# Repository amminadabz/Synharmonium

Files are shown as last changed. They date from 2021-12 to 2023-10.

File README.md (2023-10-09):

# The Synharmonium
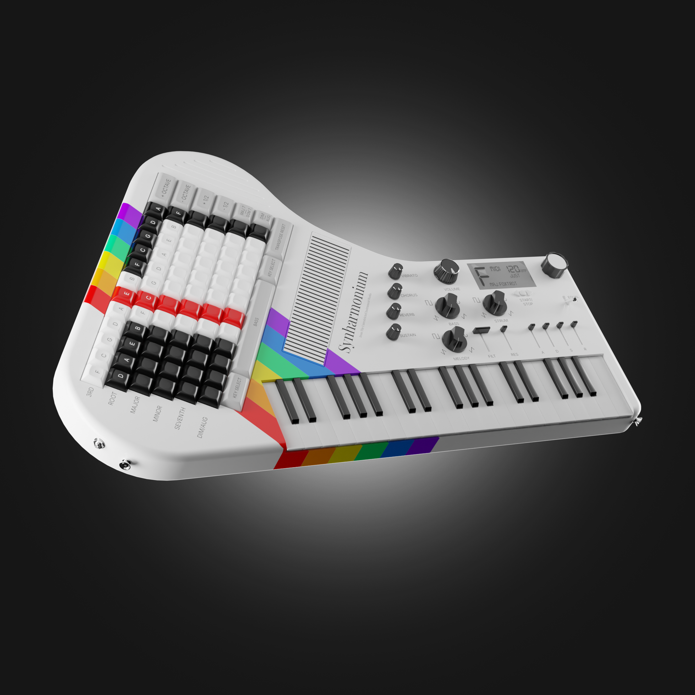
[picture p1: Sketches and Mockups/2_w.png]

#### is a new kind of musical instrument.
Designed to be easy to use, and more importantly, easy to make good music with. It uses the accordion's Stradella bass system to make it easy to play notes and chords that go well together, the Omnichord's strum plate to give texture to that harmony, and a piano keyboard for a familiar way to add a melody.

## A Well-Tempered synthesizer.
One of the goals of the Synharmonium is to create an instrument which uses an algorithmic implementation of just intonation. In other words, it tunes every note in a perfect mathematical relation to the root of whatever chord is being played. Where other instruments simply have every note an equal distance apart and call it done ("Equal Temperament"), the Synharmonium will ensure they are always in simple ratios to each other, allowing for a more resonant sound. But if you want to play _with_ those other instruments, you always have the option to disable this feature and return to the more common tuning.

## Digital where it's needed, analogue where it counts.
The Synharmonium uses a digital system to implement that tuning algorithm. But once the computer has decided what frequencies are best, everything that can analogue will be, including the envelope generators, drum machine oscillators, and effects. This allows it to have that classic analogue sound with none of the downsides.

But, if you want to use the Synharmonium's tuning technology with an external synthesizer, it also has full MIDI compatibility (with both DIN and USB).

## Free to build, modify, and hack
The hardware and software are all open source. I intend to base the control and tuning systems on an Arduino, which is beginner-friendly and hackable by design. I haven't the means to build these machines on a large scale at the moment (though I've thought about selling an "official version" as a preassembled machine and a kit, lmk what y'all think), so for the time being I will just be providing the design for free. That means you get to build it (!) until I know what I'm doing.

## A work in progress.
I'll be real with y'all: I don't know what I'm doing. Every part of this project is a skill that I am learning as I go. But I think this is a thing that deserves to exist, so I intend to let it. It will probably take some time, as I am currently pursuing degrees in Electrical Engineering and Computer Engineering, so I can only work on the Synharmonium in my free time.

If you have skills that could help this process along, feel free to join the project. Do [send me an email](mailto:uiwmusic@proton.me) first though, I'd like to know who I'm working with! 

Here goes nothin'!

-Evan

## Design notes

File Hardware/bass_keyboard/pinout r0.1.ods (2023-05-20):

floppy pin | breadboard pin | arduino pin | value
1 | E1 | +5V | VCC
2 | E2 | 22 | D92
3 | E3 | 23 | D93
4 | E4 | 24 | D94
5 | E5 | 25 | D95
6 | E6 |  | NC
7 | E7 |  | NC
8 | E8 |  | NC
9 | E9 |  | NC
10 | E10 |  | NC
11 | E11 |  | NC
12 | E12 | 27 | ROW5
13 | E13 | 28 | ROW4
14 | E14 | 29 | ROW3
15 | E15 | 30 | ROW2
16 | E16 | 31 | ROW1
17 | E17 | 32 | ROW0
18 | F1 |  | NC
19 | F2 | GND | LS1-
20 | F3 | 13 | LS1+
21 | F4 | 33 | COL12
22 | F5 | 34 | COL11
23 | F6 | 35 | COL10
24 | F7 | 36 | COL9
25 | F8 | 37 | COL8
26 | F9 | 38 | COL7
27 | F10 | 39 | COL6
28 | F11 | 40 | COL5
29 | F12 | 41 | COL4
30 | F13 | 42 | COL3
31 | F14 | 43 | COL2
32 | F15 | 44 | COL1
33 | F16 | 45 | COL0
34 | F17 | 26 | ROW6

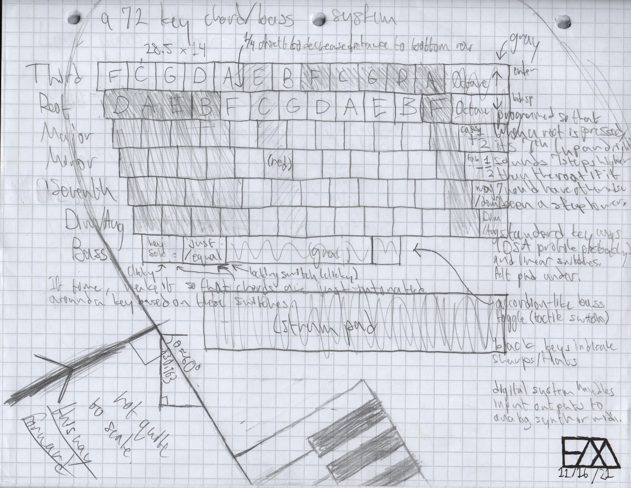
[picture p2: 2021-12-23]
Sketches and Mockups/synharmonium-sketch-1.jpg

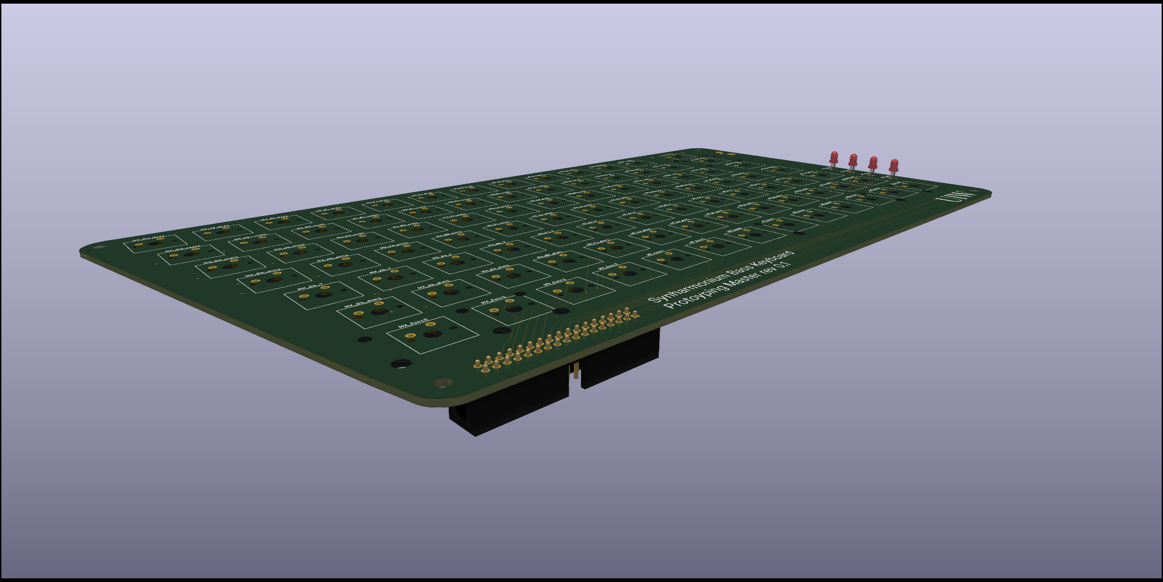
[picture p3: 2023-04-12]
Sketches and Mockups/bass_keyboard_pcb_render_frontdiag.png

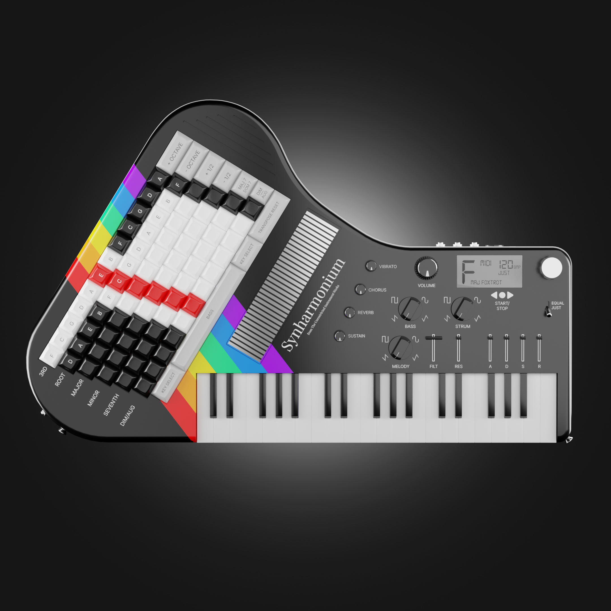
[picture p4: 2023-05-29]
Sketches and Mockups/1_b.png

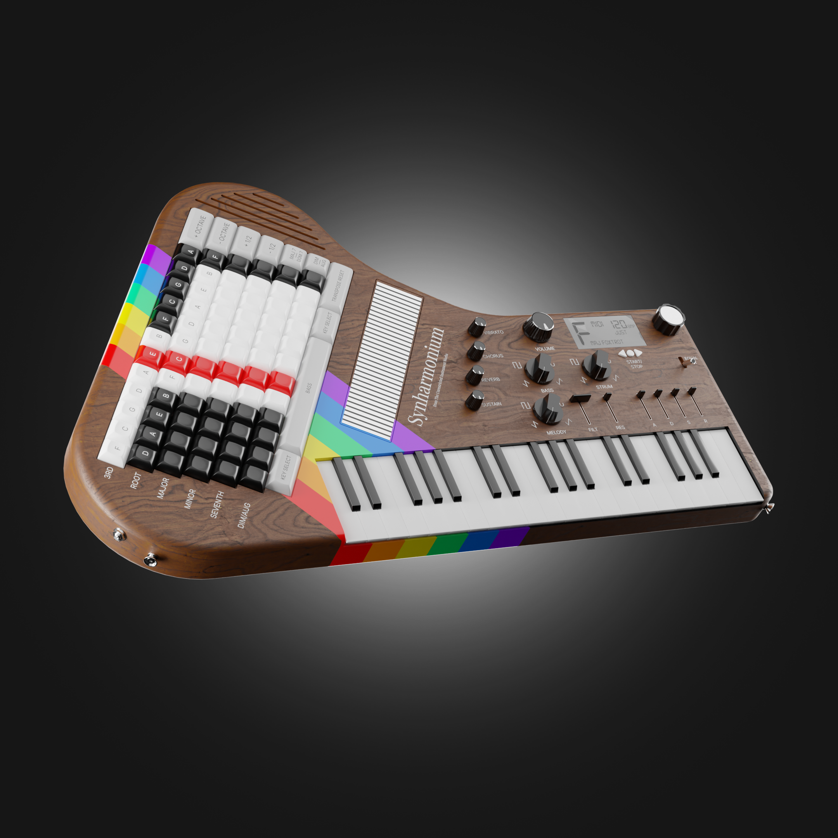
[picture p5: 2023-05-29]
Sketches and Mockups/2_wood.png

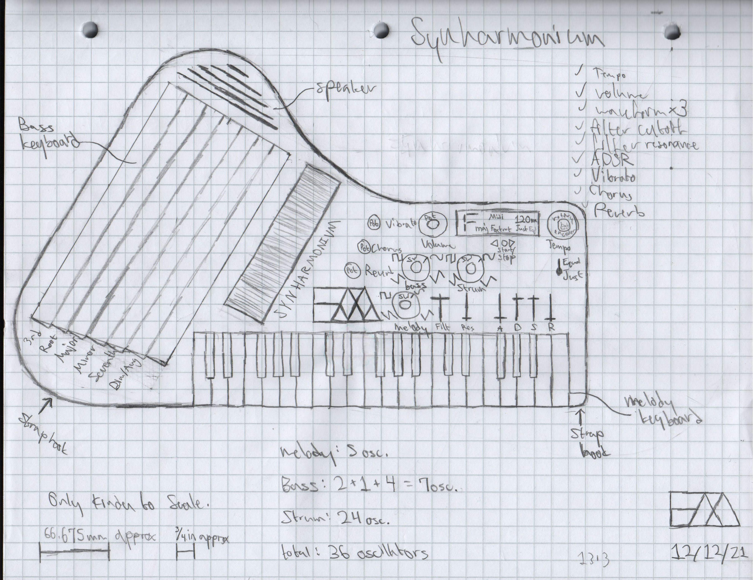
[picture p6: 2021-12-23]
Sketches and Mockups/synharmonium-sketch-2.jpg

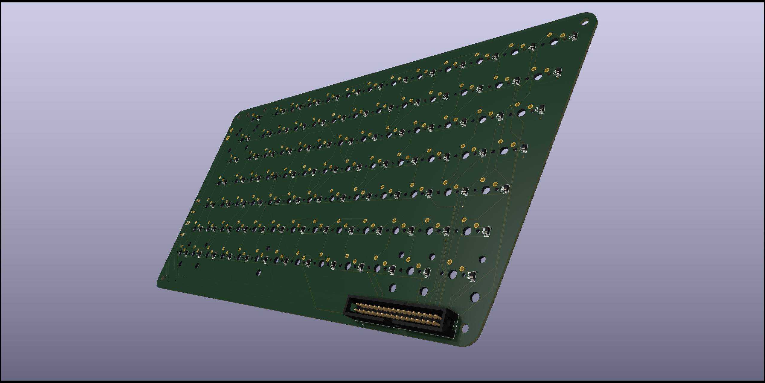
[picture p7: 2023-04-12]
Sketches and Mockups/bass_keyboard_pcb_render_backdiag.png

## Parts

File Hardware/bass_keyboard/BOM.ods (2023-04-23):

UIW
 |  | ™ | The Unrestricted Instrumentworks
 |  |  | Synharmonium |  |  |  |  | Evan Mobley
 |  |  | Bass Keyboard, Prototyping master Rev 0.1 |  |  |  |  | 4-18-23
Item # | *Designator | *Qty | Manufacturer | *Mfg Part # | Description / Value | *Package/Footprint | Type | Your Instructions / Notes
1 | D1 – D91 | 91 | Micro Commercial Co | 1N4148W-TP | Diode 100 V 150mA Surface Mount SOD-123 | SOD-123 | SMD
2 | J1 | 1 | On Shore Technology Inc. | 302-S341 | CONN HEADER VERT 34POS 2.54MM |  | Through-hole | Keying slot towards board edge

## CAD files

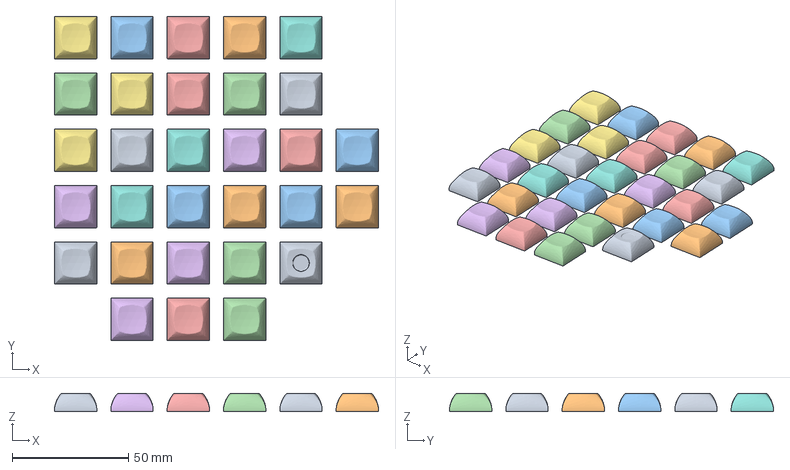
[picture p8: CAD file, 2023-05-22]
Hardware/bass_keyboard/Prototype Keycap Models/DSA/Black/1.3mf
139.2 x 139.2 x 7.91 mm
1.00homing

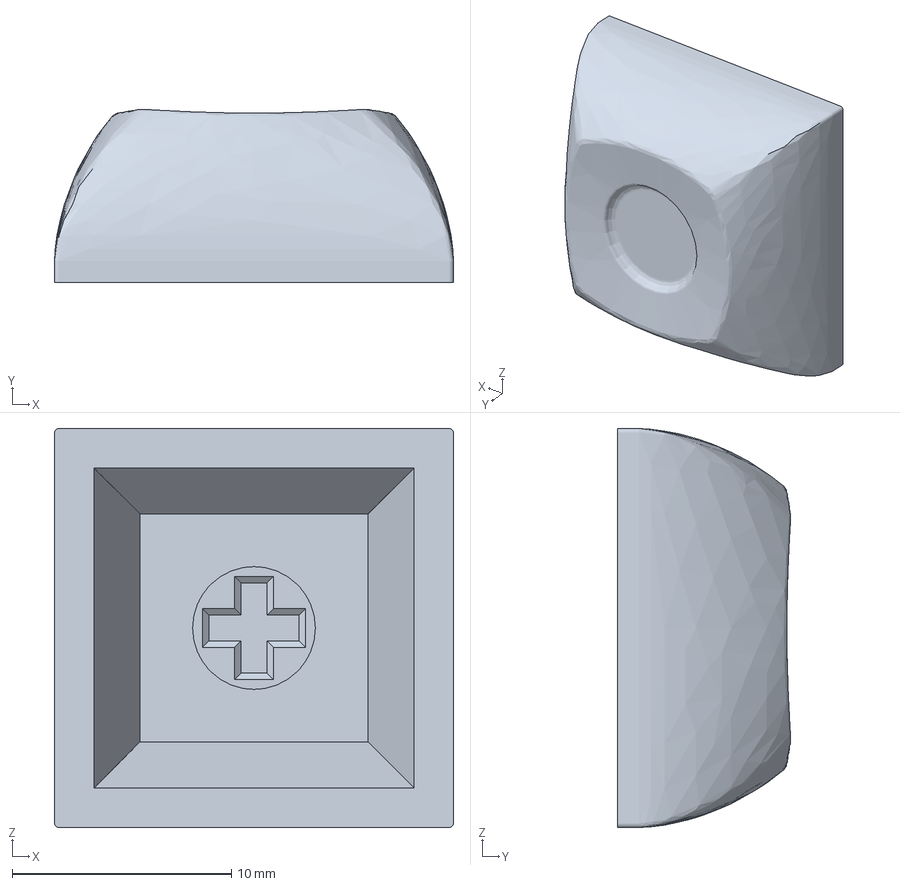
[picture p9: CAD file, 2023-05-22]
Hardware/bass_keyboard/Prototype Keycap Models/DSA/Black/1x/1.00homing.3mf
18.2 x 7.91 x 18.2 mm

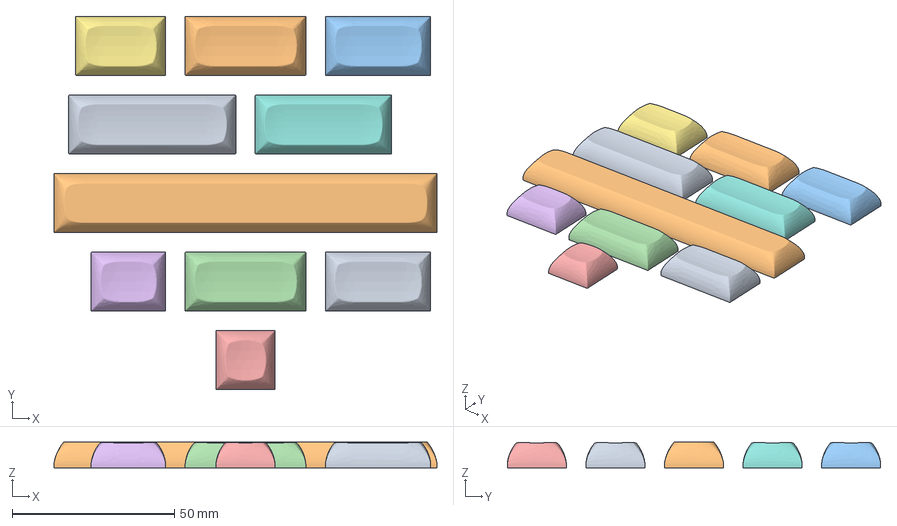
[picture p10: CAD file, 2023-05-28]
Hardware/bass_keyboard/Prototype Keycap Models/DSA/Light Gray/1.3mf
117.9 x 115.0 x 8.00 mm

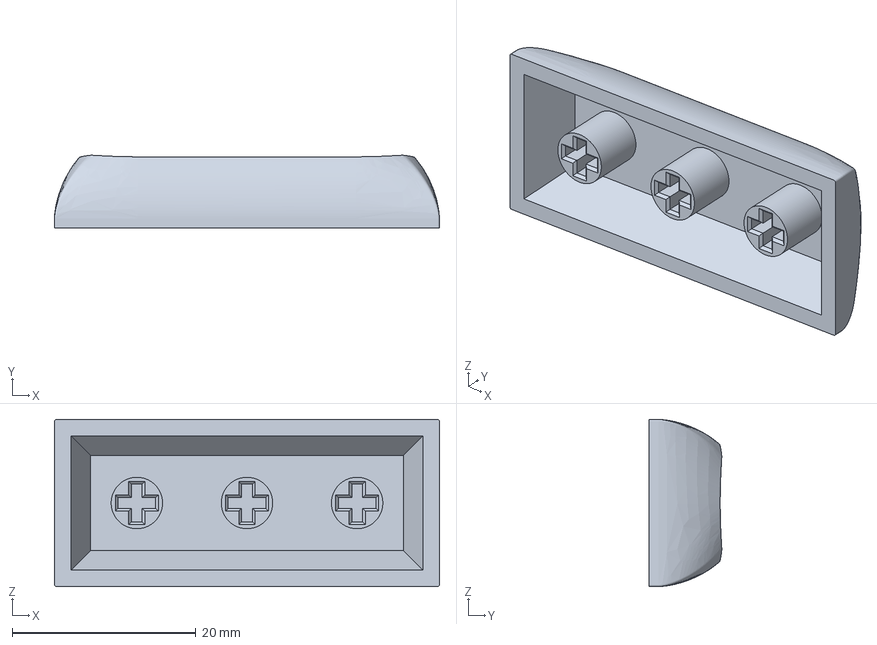
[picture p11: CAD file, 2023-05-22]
Hardware/bass_keyboard/Prototype Keycap Models/DSA/Light Gray/1x/2.25.3mf
42.0 x 7.91 x 18.2 mm

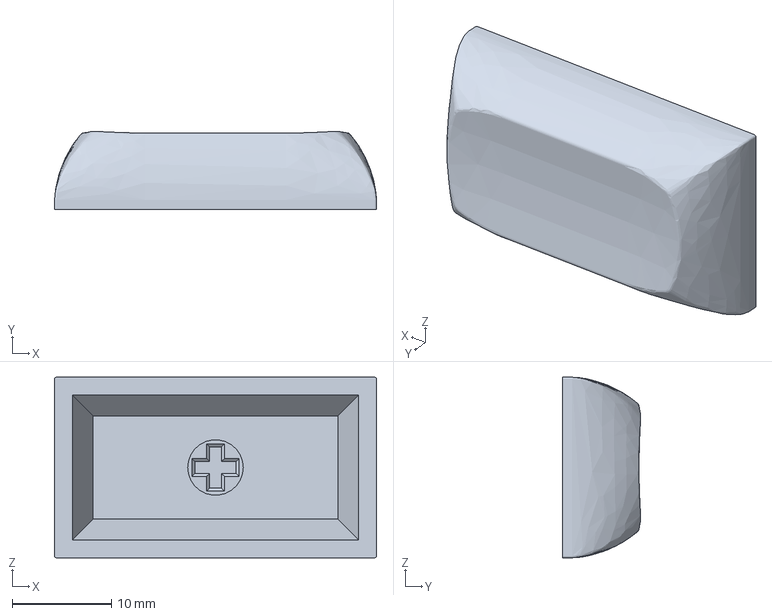
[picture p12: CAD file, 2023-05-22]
Hardware/bass_keyboard/Prototype Keycap Models/DSA/Light Gray/2x/1.75.3mf
32.5 x 7.91 x 18.2 mm

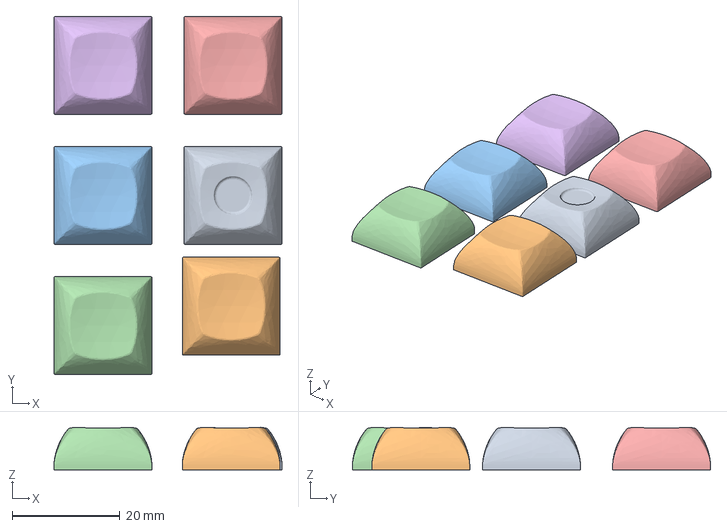
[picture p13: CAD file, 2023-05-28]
Hardware/bass_keyboard/Prototype Keycap Models/DSA/Red/1.3mf
42.4 x 66.6 x 7.91 mm
1.00_homing

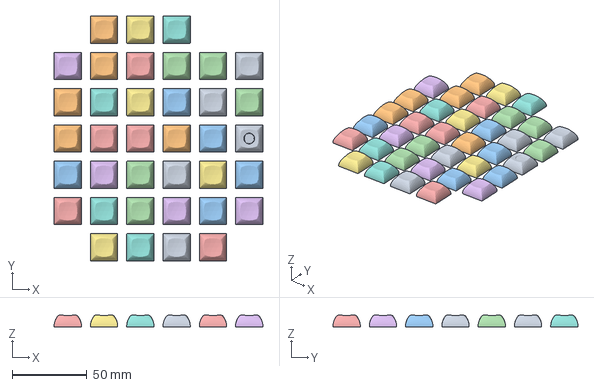
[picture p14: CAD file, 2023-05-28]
Hardware/bass_keyboard/Prototype Keycap Models/DSA/White/1.3mf
139.2 x 163.4 x 7.91 mm
1.00_homing

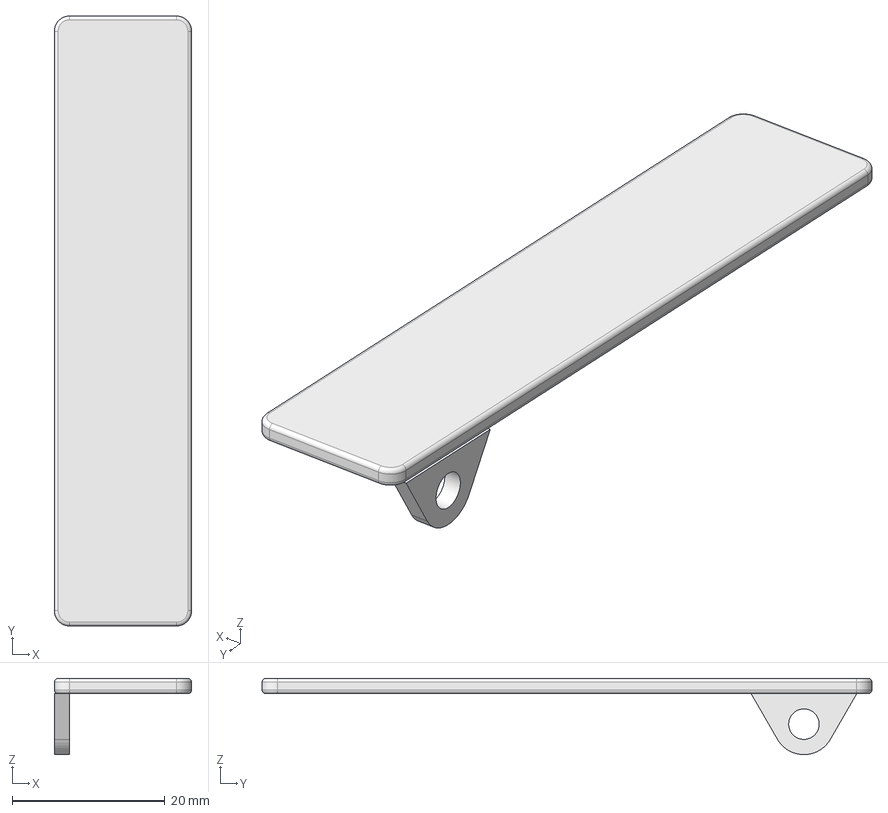
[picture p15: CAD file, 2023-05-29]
Hardware/melody_keyboard/keymodel_topC.FCStd
18.0 x 80.0 x 9.99 mm

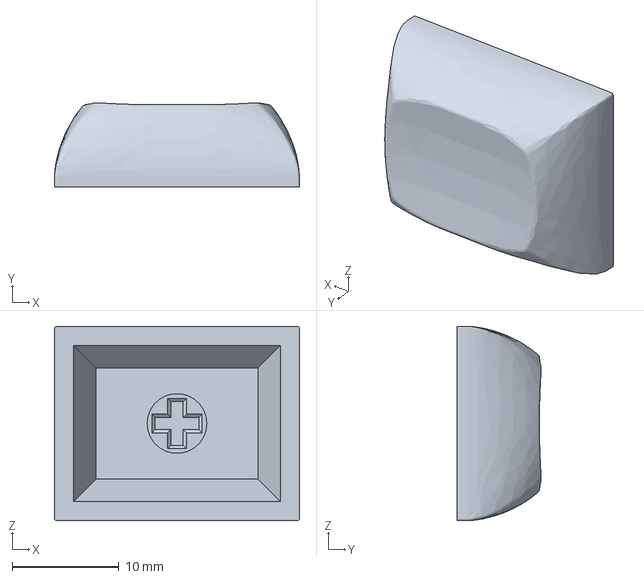
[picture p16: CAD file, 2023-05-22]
Hardware/bass_keyboard/Prototype Keycap Models/DSA/Light Gray/1x/1.25.3mf
22.9 x 7.91 x 18.2 mm

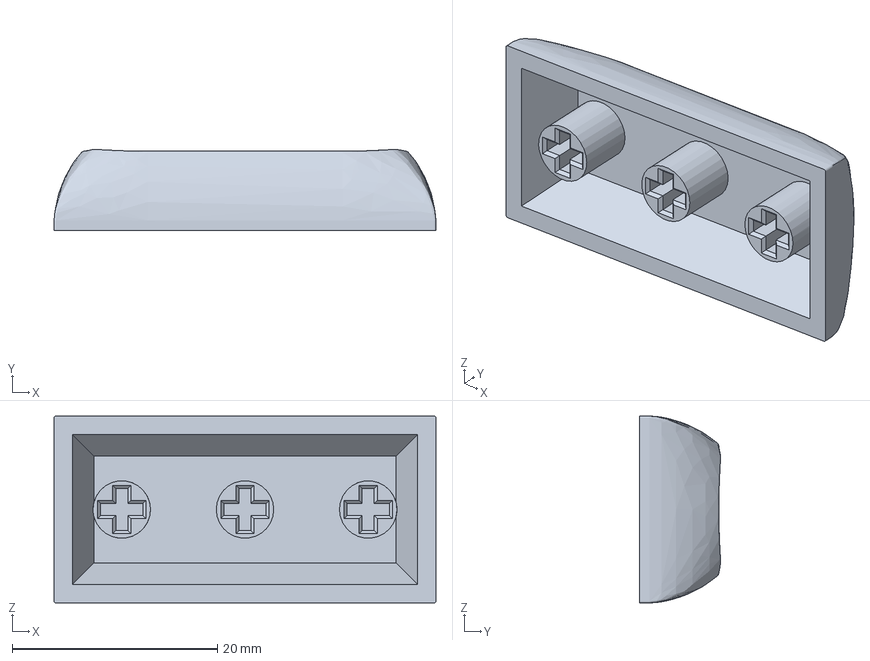
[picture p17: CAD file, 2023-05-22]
Hardware/bass_keyboard/Prototype Keycap Models/DSA/Light Gray/2x/2.00.3mf
37.2 x 7.91 x 18.2 mm

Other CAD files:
Hardware/bass_keyboard/Prototype Keycap Models/DSA/Black/29x/DSA 1u.step
Hardware/bass_keyboard/Prototype Keycap Models/DSA/Red/1x/1.00_homing.3mf
Hardware/bass_keyboard/Prototype Keycap Models/DSA/Red/5x/1.00.3mf
Hardware/bass_keyboard/Prototype Keycap Models/DSA/White/1x/1.00_homing.3mf
Hardware/bass_keyboard/Prototype Keycap Models/DSA/White/36/1.00.3mf
Hardware/bass_keyboard/Prototype Keycap Models/DSA/Black/1x/1.00.3mf
Hardware/bass_keyboard/Prototype Keycap Models/DSA/Red/1x/DSA 1u homing.step
Hardware/bass_keyboard/Prototype Keycap Models/DSA/Red/5x/DSA 1u.step
Hardware/bass_keyboard/Prototype Keycap Models/DSA/Black/1x/DSA 1u homing.step
Hardware/bass_keyboard/Prototype Keycap Models/DSA/Light Gray/1x/1.00.3mf
Hardware/bass_keyboard/Prototype Keycap Models/DSA/Light Gray/1x/1.50.3mf
Hardware/bass_keyboard/Prototype Keycap Models/DSA/Light Gray/1x/2.75.3mf
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

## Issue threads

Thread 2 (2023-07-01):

Firmware: no keypress recognition

amminadabz, 2023-07-01:
When the prototype keyboard is connected, the serial monitor shows output from the loop counter function, but none from any keypresses. Connectivity has been thoroughly checked once, and I'm liable to do it again, but it's safe to assume there's an issue in the firmware considering that I wrote it.

amminadabz, 2023-07-19:
I just found something strange.

I connected an LED to one of the column pins to see whether the MCU was sending scanning voltage, and it was. Then I put it in parallel to a row pin to see if the switches were returning that scanning voltage when pressed, and they were. Then I noticed that whenever I added the led to a row pin, the serial monitor showed keypresses for all the keys on that row, and the inverse when I removed the LED.

So, apparently, this whole time the key matrix library has been designed to work with a pull down resistor rather than reading return voltage. The bass keyboard circuit is modeled after mechanical keyboards, so it was not designed for pull down resistors.

Now, either parts of the library will have to be rewritten or one meant for a keyboard-style circuit will have to be found.

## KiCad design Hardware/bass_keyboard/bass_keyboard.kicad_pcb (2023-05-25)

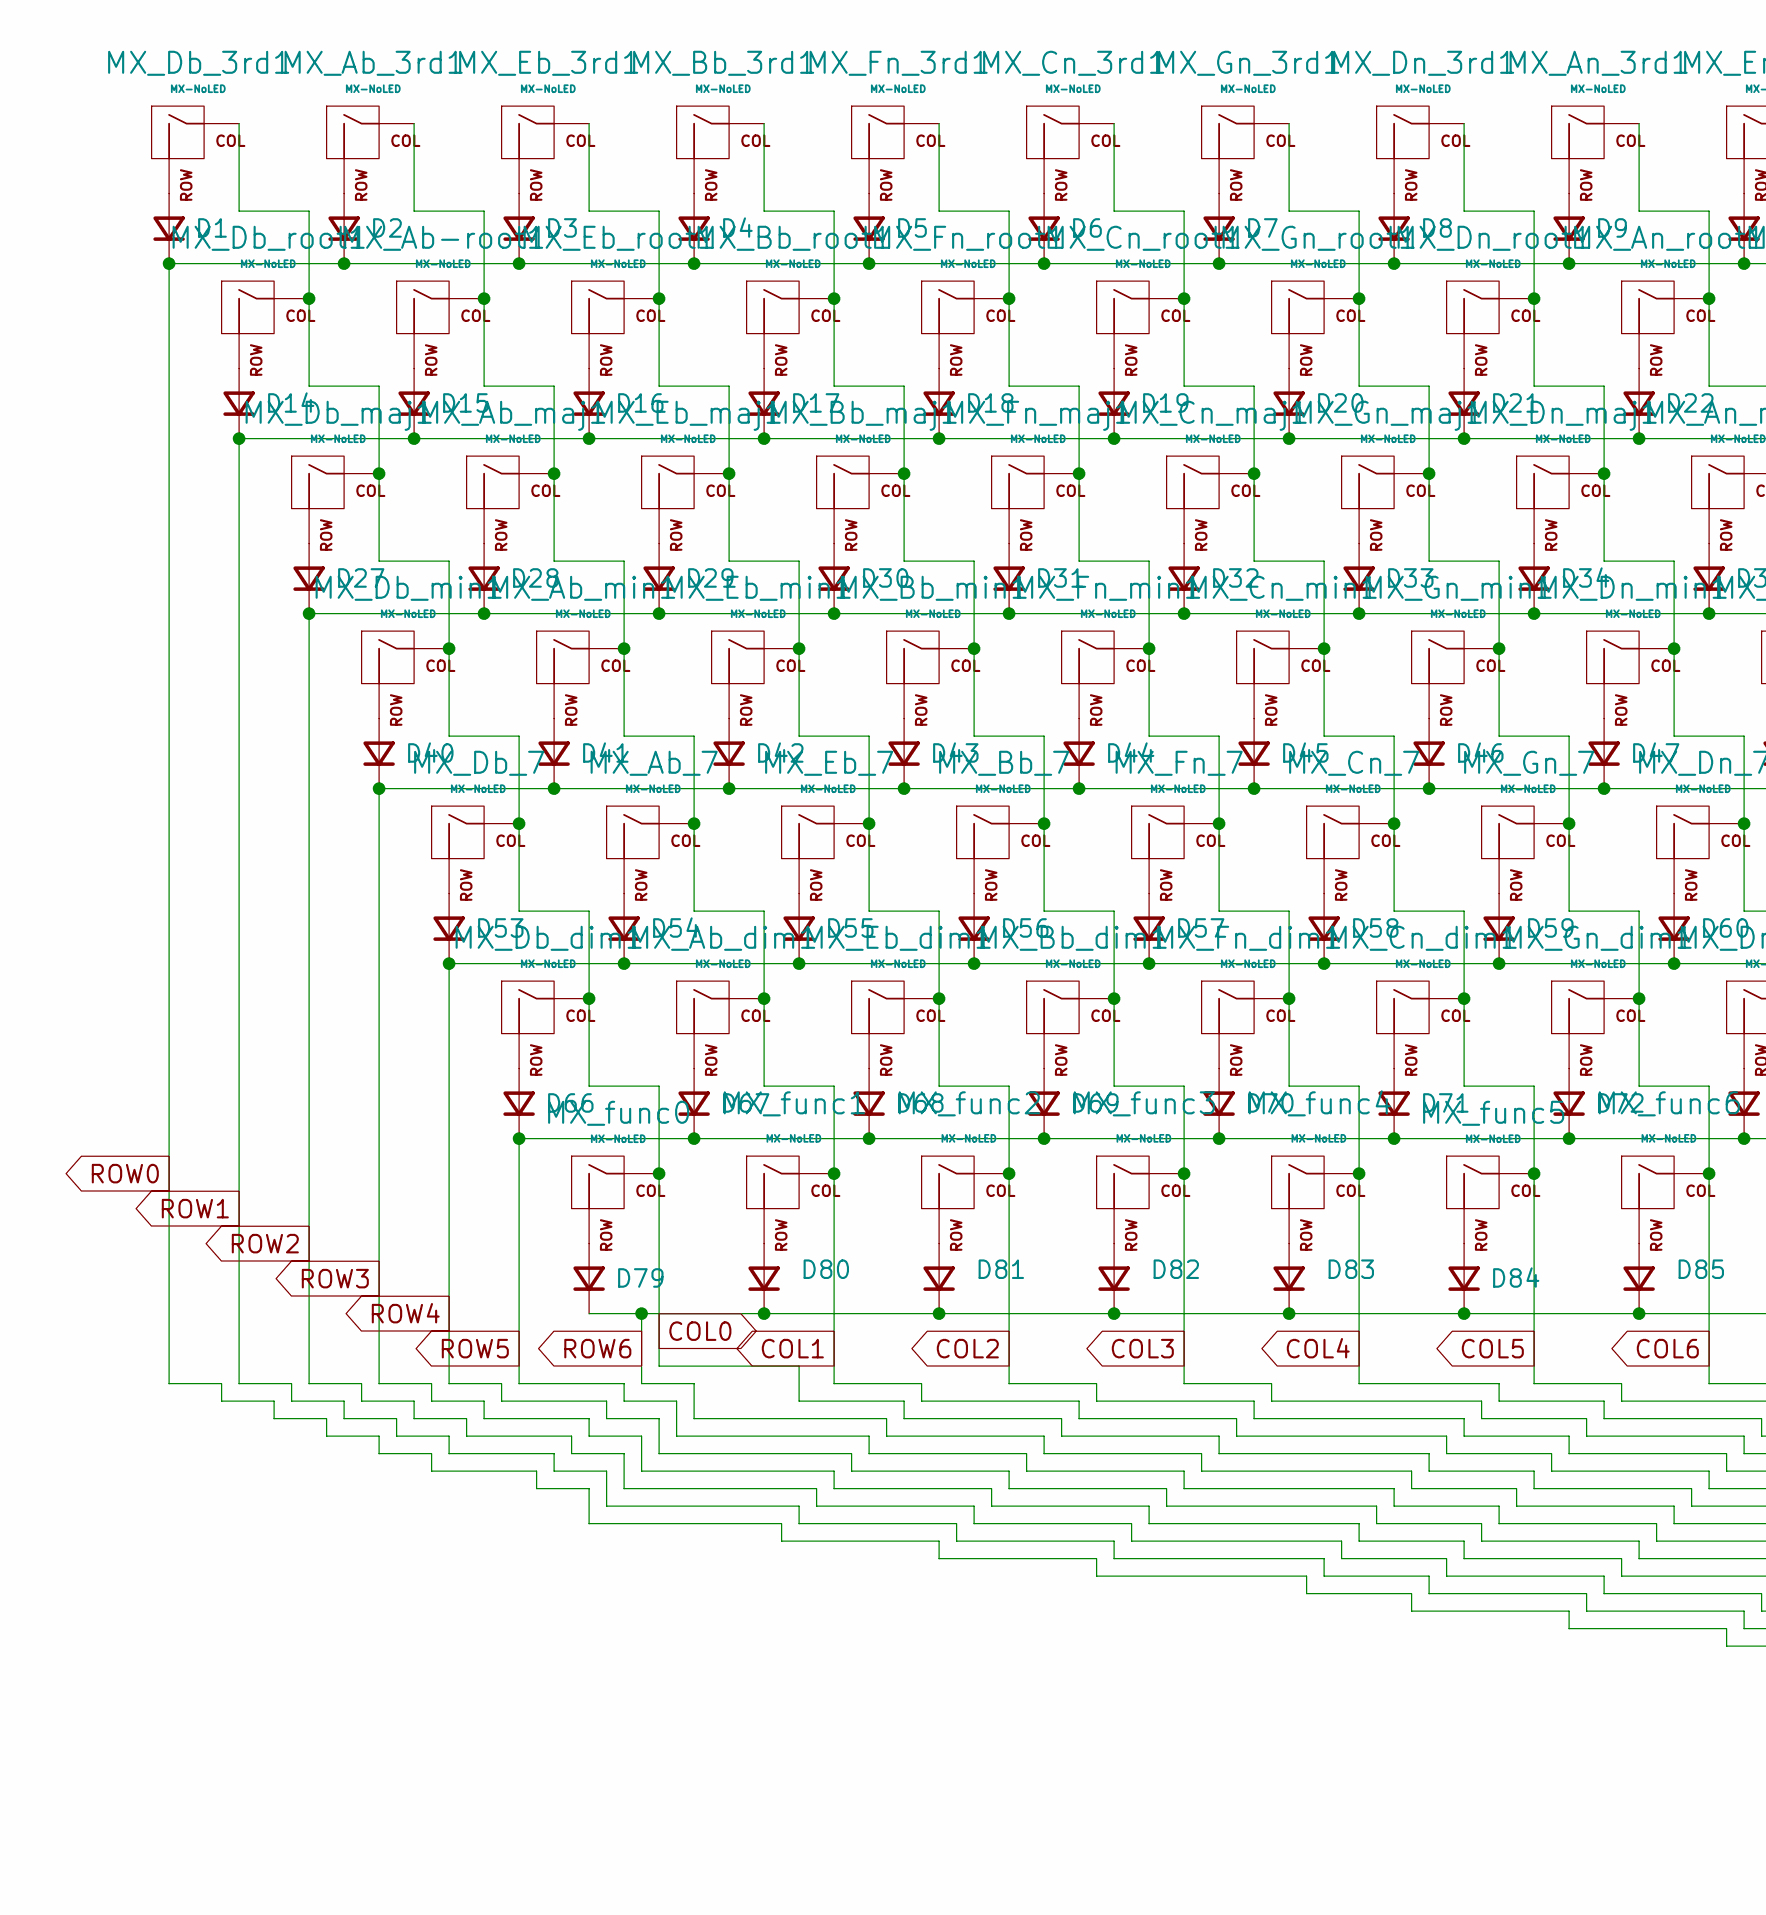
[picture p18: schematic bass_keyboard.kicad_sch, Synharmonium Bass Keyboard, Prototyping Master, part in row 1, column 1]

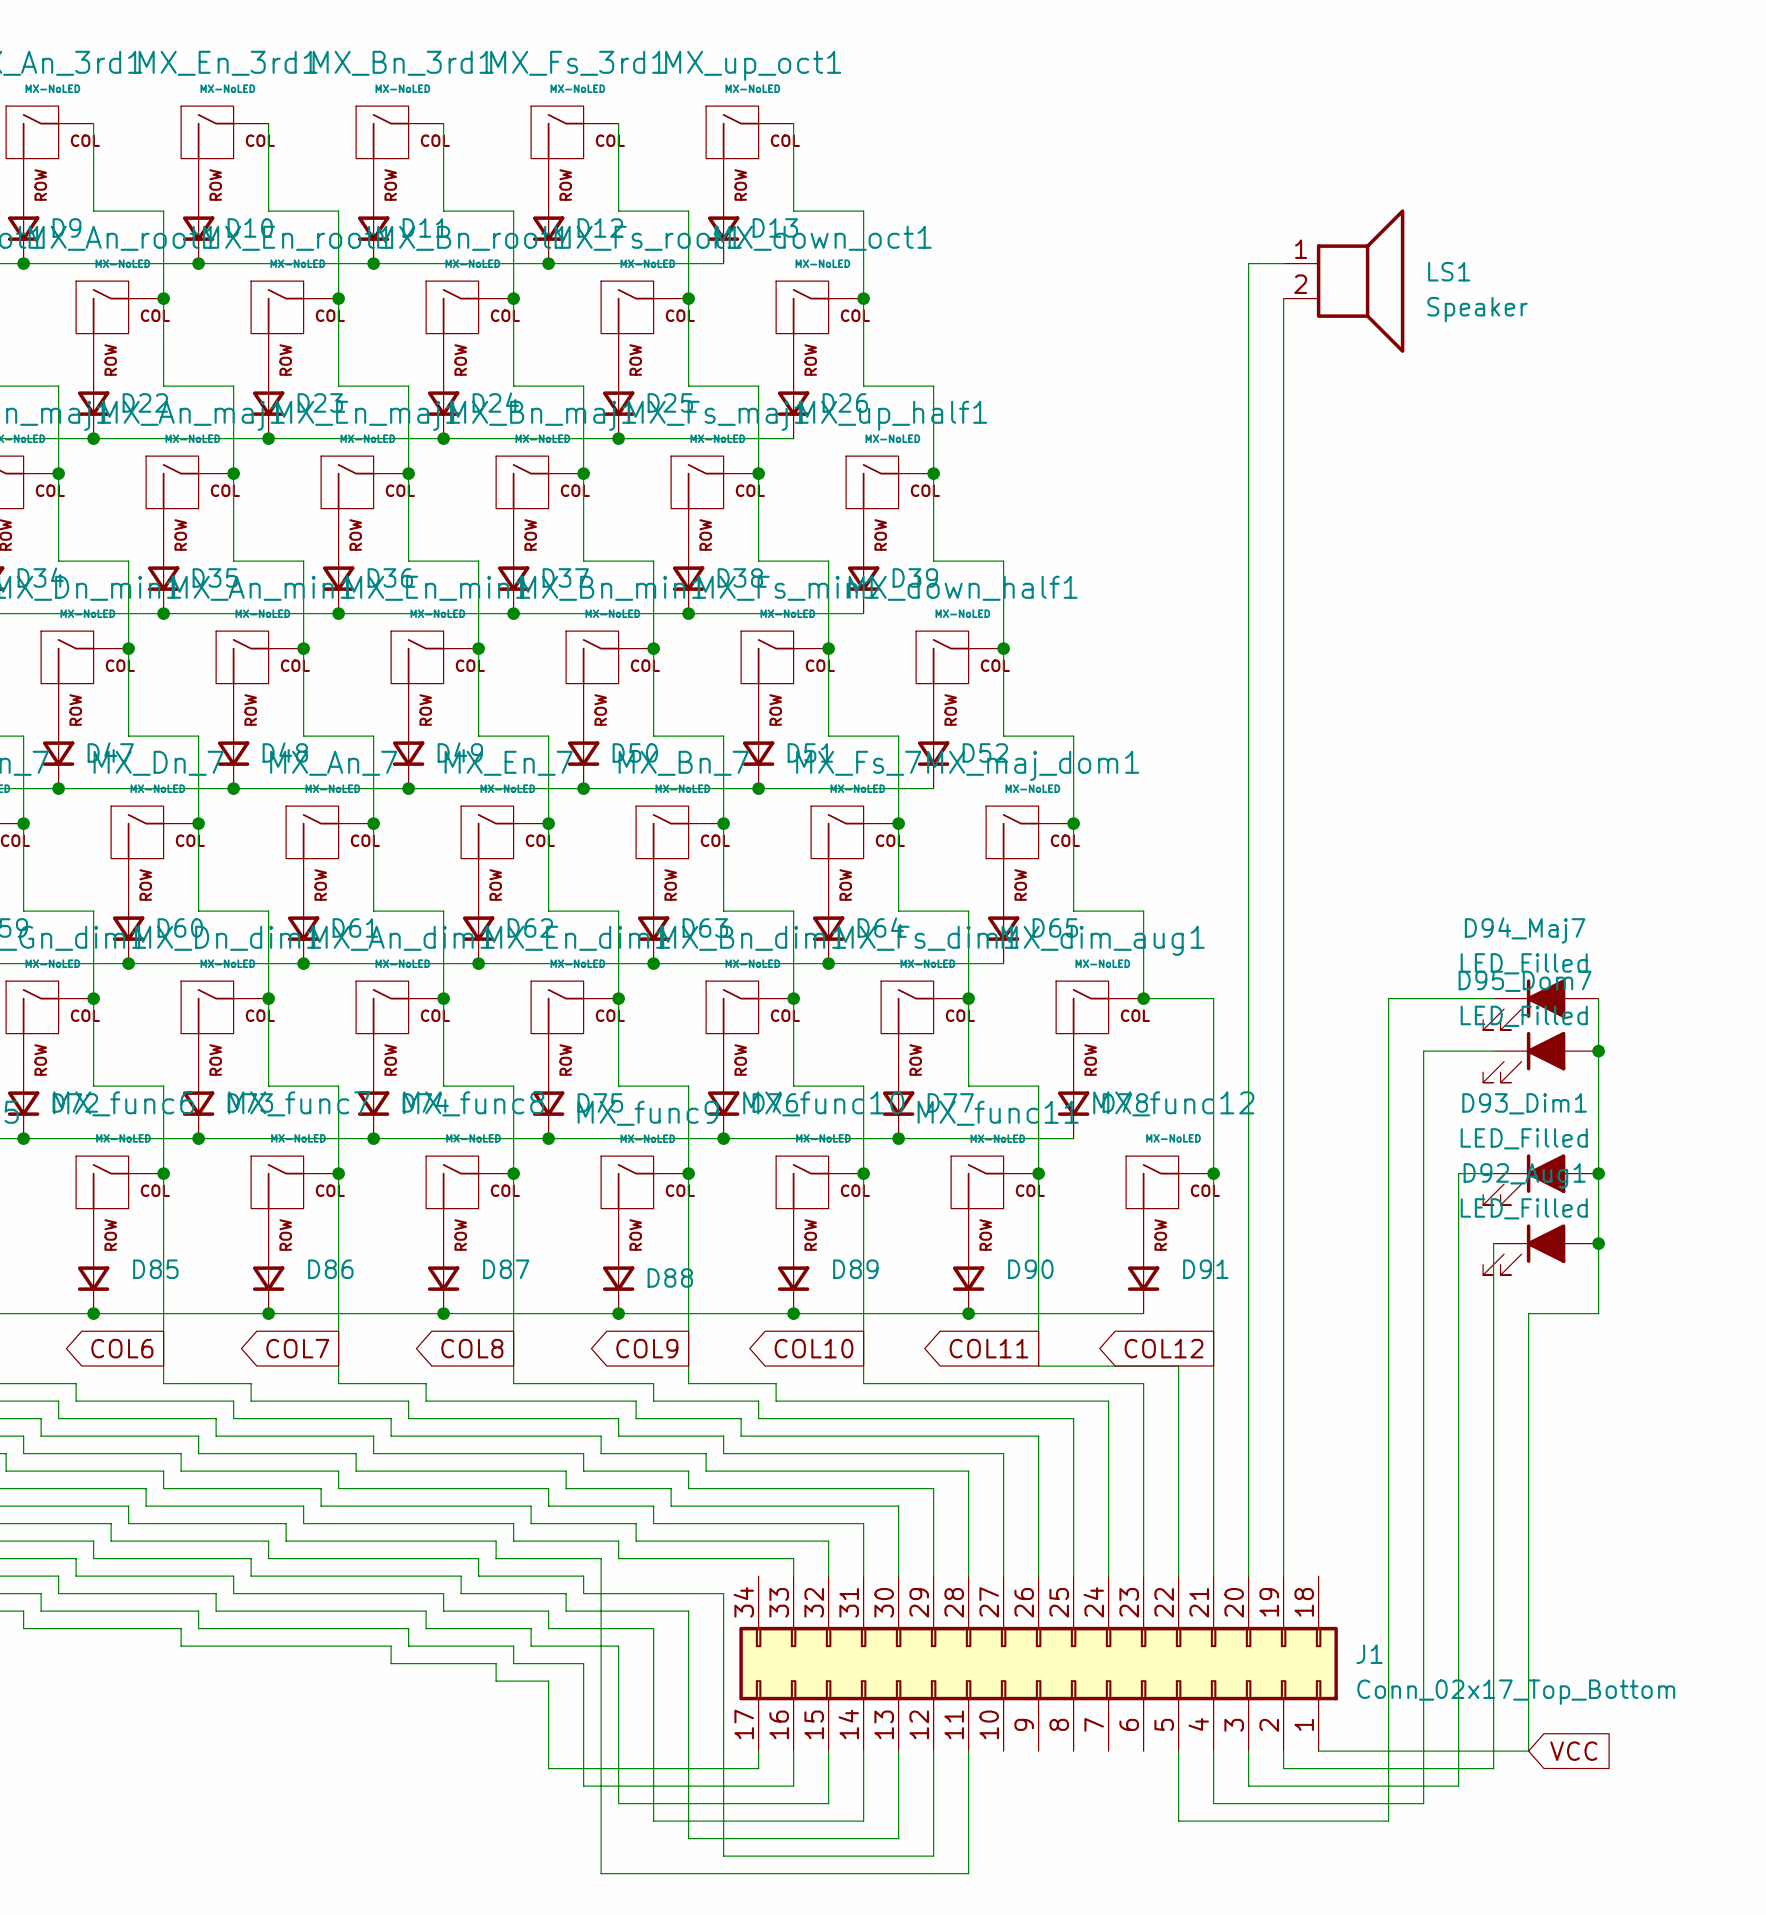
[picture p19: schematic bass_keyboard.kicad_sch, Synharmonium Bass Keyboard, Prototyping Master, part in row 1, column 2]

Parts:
D1, D2, D3, D4, D5, D6, D7, D8, D9, D10, D11, D12, D13, D14, D15, D16, D17, D18, D19, D20, D21, D22, D23, D24, D25, D26, D27, D28, D29, D30, D31, D32, D33, D34, D35, D36, D37, D38, D39, D40, D41, D42, D43, D44, D45, D46, D47, D48, D49, D50, D51, D52, D53, D54, D55, D56, D57, D58, D59, D60, D61, D62, D63, D64, D65, D66, D67, D68, D69, D70, D71, D72, D73, D74, D75, D76, D77, D78, D79, D80, D81, D82, D83, D84, D85, D86, D87, D88, D89, D90, D91: D_Small; D_SOD-123
D92_Aug1, D93_Dim1, D94_Maj7, D95_Dom7: LED_Filled; LED_D3.0mm-Pretty
J1: Conn_02x17_Top_Bottom; IDC-Header_2x17_P2.54mm_Vertical
LS1: Speaker; SolderWire-1sqmm_1x02_P5.4mm_D1.4mm_OD2.7mm
MX_Ab-root1: MX-NoLED; SW_Cherry_MX_1.00u_PCB
MX_Ab_3rd1, MX_Ab_7: MX-NoLED; SW_Cherry_MX_1.00u_PCB
MX_Ab_dim1: MX-NoLED; SW_Cherry_MX_1.00u_PCB
MX_Ab_maj1: MX-NoLED; SW_Cherry_MX_1.00u_PCB
MX_Ab_min1: MX-NoLED; SW_Cherry_MX_1.00u_PCB
MX_An_3rd1, MX_An_7: MX-NoLED; SW_Cherry_MX_1.00u_PCB
MX_An_dim1: MX-NoLED; SW_Cherry_MX_1.00u_PCB
MX_An_maj1: MX-NoLED; SW_Cherry_MX_1.00u_PCB
MX_An_min1: MX-NoLED; SW_Cherry_MX_1.00u_PCB
MX_An_root1: MX-NoLED; SW_Cherry_MX_1.00u_PCB
MX_Bb_3rd1, MX_Bb_7: MX-NoLED; SW_Cherry_MX_1.00u_PCB
MX_Bb_dim1: MX-NoLED; SW_Cherry_MX_1.00u_PCB
MX_Bb_maj1: MX-NoLED; SW_Cherry_MX_1.00u_PCB
MX_Bb_min1: MX-NoLED; SW_Cherry_MX_1.00u_PCB
MX_Bb_root1: MX-NoLED; SW_Cherry_MX_1.00u_PCB
MX_Bn_3rd1, MX_Bn_7: MX-NoLED; SW_Cherry_MX_1.00u_PCB
MX_Bn_dim1: MX-NoLED; SW_Cherry_MX_1.00u_PCB
MX_Bn_maj1: MX-NoLED; SW_Cherry_MX_1.00u_PCB
MX_Bn_min1: MX-NoLED; SW_Cherry_MX_1.00u_PCB
MX_Bn_root1: MX-NoLED; SW_Cherry_MX_1.00u_PCB
MX_Cn_3rd1, MX_Cn_7: MX-NoLED; SW_Cherry_MX_1.00u_PCB
MX_Cn_dim1: MX-NoLED; SW_Cherry_MX_1.00u_PCB
MX_Cn_maj1: MX-NoLED; SW_Cherry_MX_1.00u_PCB
MX_Cn_min1: MX-NoLED; SW_Cherry_MX_1.00u_PCB
MX_Cn_root1: MX-NoLED; SW_Cherry_MX_1.00u_PCB
MX_Db_3rd1, MX_Db_7: MX-NoLED; SW_Cherry_MX_1.00u_PCB
MX_Db_dim1: MX-NoLED; SW_Cherry_MX_1.00u_PCB
MX_Db_maj1: MX-NoLED; SW_Cherry_MX_1.00u_PCB
MX_Db_min1: MX-NoLED; SW_Cherry_MX_1.00u_PCB
MX_Db_root1: MX-NoLED; SW_Cherry_MX_1.00u_PCB
MX_Dn_3rd1, MX_Dn_7: MX-NoLED; SW_Cherry_MX_1.00u_PCB
MX_Dn_dim1: MX-NoLED; SW_Cherry_MX_1.00u_PCB
MX_Dn_maj1: MX-NoLED; SW_Cherry_MX_1.00u_PCB
MX_Dn_min1: MX-NoLED; SW_Cherry_MX_1.00u_PCB
MX_Dn_root1: MX-NoLED; SW_Cherry_MX_1.00u_PCB
MX_Eb_3rd1, MX_Eb_7: MX-NoLED; SW_Cherry_MX_1.00u_PCB
MX_Eb_dim1: MX-NoLED; SW_Cherry_MX_1.00u_PCB
MX_Eb_maj1: MX-NoLED; SW_Cherry_MX_1.00u_PCB
MX_Eb_min1: MX-NoLED; SW_Cherry_MX_1.00u_PCB
MX_Eb_root1: MX-NoLED; SW_Cherry_MX_1.00u_PCB
MX_En_3rd1, MX_En_7: MX-NoLED; SW_Cherry_MX_1.00u_PCB
MX_En_dim1: MX-NoLED; SW_Cherry_MX_1.00u_PCB
MX_En_maj1: MX-NoLED; SW_Cherry_MX_1.00u_PCB
MX_En_min1: MX-NoLED; SW_Cherry_MX_1.00u_PCB
MX_En_root1: MX-NoLED; SW_Cherry_MX_1.00u_PCB
MX_Fn_3rd1, MX_Fn_7: MX-NoLED; SW_Cherry_MX_1.00u_PCB
MX_Fn_dim1: MX-NoLED; SW_Cherry_MX_1.00u_PCB
MX_Fn_maj1: MX-NoLED; SW_Cherry_MX_1.00u_PCB
MX_Fn_min1: MX-NoLED; SW_Cherry_MX_1.00u_PCB
MX_Fn_root1: MX-NoLED; SW_Cherry_MX_1.00u_PCB
MX_Fs_3rd1, MX_Fs_7: MX-NoLED; SW_Cherry_MX_1.00u_PCB
MX_Fs_dim1: MX-NoLED; SW_Cherry_MX_1.00u_PCB
MX_Fs_maj1: MX-NoLED; SW_Cherry_MX_1.00u_PCB
MX_Fs_min1: MX-NoLED; SW_Cherry_MX_1.00u_PCB
MX_Fs_root1: MX-NoLED; SW_Cherry_MX_1.00u_PCB
MX_Gn_3rd1, MX_Gn_7: MX-NoLED; SW_Cherry_MX_1.00u_PCB
MX_Gn_dim1: MX-NoLED; SW_Cherry_MX_1.00u_PCB
MX_Gn_maj1: MX-NoLED; SW_Cherry_MX_1.00u_PCB
MX_Gn_min1: MX-NoLED; SW_Cherry_MX_1.00u_PCB
MX_Gn_root1: MX-NoLED; SW_Cherry_MX_1.00u_PCB
MX_dim_aug1: MX-NoLED; SW_Cherry_MX_1.00u_PCB
MX_down_half1: MX-NoLED; SW_Cherry_MX_1.00u_PCB
MX_down_oct1: MX-NoLED; SW_Cherry_MX_1.00u_PCB
MX_func0, MX_func1, MX_func2, MX_func3, MX_func4, MX_func5, MX_func6, MX_func7, MX_func8, MX_func9, MX_func10, MX_func11, MX_func12: MX-NoLED; SW_Cherry_MX_1.00u_PCB
MX_maj_dom1: MX-NoLED; SW_Cherry_MX_1.00u_PCB
MX_up_half1: MX-NoLED; SW_Cherry_MX_1.00u_PCB
MX_up_oct1: MX-NoLED; SW_Cherry_MX_1.00u_PCB

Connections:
COL0: J1.33, MX_Db_3rd1.1 (COL), MX_Db_7.1 (COL), MX_Db_dim1.1 (COL), MX_Db_maj1.1 (COL), MX_Db_min1.1 (COL), MX_Db_root1.1 (COL), MX_func0.1 (COL)
COL1: J1.32, MX_Ab-root1.1 (COL), MX_Ab_3rd1.1 (COL), MX_Ab_7.1 (COL), MX_Ab_dim1.1 (COL), MX_Ab_maj1.1 (COL), MX_Ab_min1.1 (COL), MX_func1.1 (COL)
COL2: J1.31, MX_Eb_3rd1.1 (COL), MX_Eb_7.1 (COL), MX_Eb_dim1.1 (COL), MX_Eb_maj1.1 (COL), MX_Eb_min1.1 (COL), MX_Eb_root1.1 (COL), MX_func2.1 (COL)
COL3: J1.30, MX_Bb_3rd1.1 (COL), MX_Bb_7.1 (COL), MX_Bb_dim1.1 (COL), MX_Bb_maj1.1 (COL), MX_Bb_min1.1 (COL), MX_Bb_root1.1 (COL), MX_func3.1 (COL)
COL4: J1.29, MX_Fn_3rd1.1 (COL), MX_Fn_7.1 (COL), MX_Fn_dim1.1 (COL), MX_Fn_maj1.1 (COL), MX_Fn_min1.1 (COL), MX_Fn_root1.1 (COL), MX_func4.1 (COL)
COL5: J1.28, MX_Cn_3rd1.1 (COL), MX_Cn_7.1 (COL), MX_Cn_dim1.1 (COL), MX_Cn_maj1.1 (COL), MX_Cn_min1.1 (COL), MX_Cn_root1.1 (COL), MX_func5.1 (COL)
COL6: J1.27, MX_Gn_3rd1.1 (COL), MX_Gn_7.1 (COL), MX_Gn_dim1.1 (COL), MX_Gn_maj1.1 (COL), MX_Gn_min1.1 (COL), MX_Gn_root1.1 (COL), MX_func6.1 (COL)
COL7: J1.26, MX_Dn_3rd1.1 (COL), MX_Dn_7.1 (COL), MX_Dn_dim1.1 (COL), MX_Dn_maj1.1 (COL), MX_Dn_min1.1 (COL), MX_Dn_root1.1 (COL), MX_func7.1 (COL)
COL8: J1.25, MX_An_3rd1.1 (COL), MX_An_7.1 (COL), MX_An_dim1.1 (COL), MX_An_maj1.1 (COL), MX_An_min1.1 (COL), MX_An_root1.1 (COL), MX_func8.1 (COL)
COL9: J1.24, MX_En_3rd1.1 (COL), MX_En_7.1 (COL), MX_En_dim1.1 (COL), MX_En_maj1.1 (COL), MX_En_min1.1 (COL), MX_En_root1.1 (COL), MX_func9.1 (COL)
COL10: J1.23, MX_Bn_3rd1.1 (COL), MX_Bn_7.1 (COL), MX_Bn_dim1.1 (COL), MX_Bn_maj1.1 (COL), MX_Bn_min1.1 (COL), MX_Bn_root1.1 (COL), MX_func10.1 (COL)
COL11: J1.22, MX_Fs_3rd1.1 (COL), MX_Fs_7.1 (COL), MX_Fs_dim1.1 (COL), MX_Fs_maj1.1 (COL), MX_Fs_min1.1 (COL), MX_Fs_root1.1 (COL), MX_func11.1 (COL)
COL12: J1.21, MX_dim_aug1.1 (COL), MX_down_half1.1 (COL), MX_down_oct1.1 (COL), MX_func12.1 (COL), MX_maj_dom1.1 (COL), MX_up_half1.1 (COL), MX_up_oct1.1 (COL)
unnamed: D1.2 (A), MX_Db_3rd1.2 (ROW)
unnamed: D2.2 (A), MX_Ab_3rd1.2 (ROW)
unnamed: D3.2 (A), MX_Eb_3rd1.2 (ROW)
unnamed: D4.2 (A), MX_Bb_3rd1.2 (ROW)
unnamed: D5.2 (A), MX_Fn_3rd1.2 (ROW)
unnamed: D6.2 (A), MX_Cn_3rd1.2 (ROW)
unnamed: D7.2 (A), MX_Gn_3rd1.2 (ROW)
unnamed: D8.2 (A), MX_Dn_3rd1.2 (ROW)
unnamed: D9.2 (A), MX_An_3rd1.2 (ROW)
unnamed: D10.2 (A), MX_En_3rd1.2 (ROW)
unnamed: D11.2 (A), MX_Bn_3rd1.2 (ROW)
unnamed: D12.2 (A), MX_Fs_3rd1.2 (ROW)
unnamed: D13.2 (A), MX_up_oct1.2 (ROW)
unnamed: D14.2 (A), MX_Db_root1.2 (ROW)
unnamed: D15.2 (A), MX_Ab-root1.2 (ROW)
unnamed: D16.2 (A), MX_Eb_root1.2 (ROW)
unnamed: D17.2 (A), MX_Bb_root1.2 (ROW)
unnamed: D18.2 (A), MX_Fn_root1.2 (ROW)
unnamed: D19.2 (A), MX_Cn_root1.2 (ROW)
unnamed: D20.2 (A), MX_Gn_root1.2 (ROW)
unnamed: D21.2 (A), MX_Dn_root1.2 (ROW)
unnamed: D22.2 (A), MX_An_root1.2 (ROW)
unnamed: D23.2 (A), MX_En_root1.2 (ROW)
unnamed: D24.2 (A), MX_Bn_root1.2 (ROW)
unnamed: D25.2 (A), MX_Fs_root1.2 (ROW)
unnamed: D26.2 (A), MX_down_oct1.2 (ROW)
unnamed: D27.2 (A), MX_Db_maj1.2 (ROW)
unnamed: D28.2 (A), MX_Ab_maj1.2 (ROW)
unnamed: D29.2 (A), MX_Eb_maj1.2 (ROW)
unnamed: D30.2 (A), MX_Bb_maj1.2 (ROW)
unnamed: D31.2 (A), MX_Fn_maj1.2 (ROW)
unnamed: D32.2 (A), MX_Cn_maj1.2 (ROW)
unnamed: D33.2 (A), MX_Gn_maj1.2 (ROW)
unnamed: D34.2 (A), MX_Dn_maj1.2 (ROW)
unnamed: D35.2 (A), MX_An_maj1.2 (ROW)
unnamed: D36.2 (A), MX_En_maj1.2 (ROW)
unnamed: D37.2 (A), MX_Bn_maj1.2 (ROW)
unnamed: D38.2 (A), MX_Fs_maj1.2 (ROW)
unnamed: D39.2 (A), MX_up_half1.2 (ROW)
unnamed: D40.2 (A), MX_Db_min1.2 (ROW)
unnamed: D41.2 (A), MX_Ab_min1.2 (ROW)
unnamed: D42.2 (A), MX_Eb_min1.2 (ROW)
unnamed: D43.2 (A), MX_Bb_min1.2 (ROW)
unnamed: D44.2 (A), MX_Fn_min1.2 (ROW)
unnamed: D45.2 (A), MX_Cn_min1.2 (ROW)
unnamed: D46.2 (A), MX_Gn_min1.2 (ROW)
unnamed: D47.2 (A), MX_Dn_min1.2 (ROW)
unnamed: D48.2 (A), MX_An_min1.2 (ROW)
unnamed: D49.2 (A), MX_En_min1.2 (ROW)
unnamed: D50.2 (A), MX_Bn_min1.2 (ROW)
unnamed: D51.2 (A), MX_Fs_min1.2 (ROW)
unnamed: D52.2 (A), MX_down_half1.2 (ROW)
unnamed: D53.2 (A), MX_Db_7.2 (ROW)
unnamed: D54.2 (A), MX_Ab_7.2 (ROW)
unnamed: D55.2 (A), MX_Eb_7.2 (ROW)
unnamed: D56.2 (A), MX_Bb_7.2 (ROW)
unnamed: D57.2 (A), MX_Fn_7.2 (ROW)
unnamed: D58.2 (A), MX_Cn_7.2 (ROW)
unnamed: D59.2 (A), MX_Gn_7.2 (ROW)
unnamed: D60.2 (A), MX_Dn_7.2 (ROW)
unnamed: D61.2 (A), MX_An_7.2 (ROW)
unnamed: D62.2 (A), MX_En_7.2 (ROW)
unnamed: D63.2 (A), MX_Bn_7.2 (ROW)
unnamed: D64.2 (A), MX_Fs_7.2 (ROW)
unnamed: D65.2 (A), MX_maj_dom1.2 (ROW)
unnamed: D66.2 (A), MX_Db_dim1.2 (ROW)
unnamed: D67.2 (A), MX_Ab_dim1.2 (ROW)
unnamed: D68.2 (A), MX_Eb_dim1.2 (ROW)
unnamed: D69.2 (A), MX_Bb_dim1.2 (ROW)
unnamed: D70.2 (A), MX_Fn_dim1.2 (ROW)
unnamed: D71.2 (A), MX_Cn_dim1.2 (ROW)
unnamed: D72.2 (A), MX_Gn_dim1.2 (ROW)
unnamed: D73.2 (A), MX_Dn_dim1.2 (ROW)
unnamed: D74.2 (A), MX_An_dim1.2 (ROW)
unnamed: D75.2 (A), MX_En_dim1.2 (ROW)
unnamed: D76.2 (A), MX_Bn_dim1.2 (ROW)
unnamed: D77.2 (A), MX_Fs_dim1.2 (ROW)
unnamed: D78.2 (A), MX_dim_aug1.2 (ROW)
unnamed: D79.2 (A), MX_func0.2 (ROW)
unnamed: D80.2 (A), MX_func1.2 (ROW)
unnamed: D81.2 (A), MX_func2.2 (ROW)
unnamed: D82.2 (A), MX_func3.2 (ROW)
unnamed: D83.2 (A), MX_func4.2 (ROW)
unnamed: D84.2 (A), MX_func5.2 (ROW)
unnamed: D85.2 (A), MX_func6.2 (ROW)
unnamed: D86.2 (A), MX_func7.2 (ROW)
unnamed: D87.2 (A), MX_func8.2 (ROW)
unnamed: D88.2 (A), MX_func9.2 (ROW)
unnamed: D89.2 (A), MX_func10.2 (ROW)
unnamed: D90.2 (A), MX_func11.2 (ROW)
unnamed: D91.2 (A), MX_func12.2 (ROW)
unnamed: D92_Aug1.1 (K), J1.2
unnamed: D93_Dim1.1 (K), J1.3
unnamed: D94_Maj7.1 (K), J1.5
unnamed: D95_Dom7.1 (K), J1.4
unnamed: J1.19, LS1.2
unnamed: J1.20, LS1.1
ROW0: D1.1 (K), D2.1 (K), D3.1 (K), D4.1 (K), D5.1 (K), D6.1 (K), D7.1 (K), D8.1 (K), D9.1 (K), D10.1 (K), D11.1 (K), D12.1 (K), D13.1 (K), J1.17
ROW1: D14.1 (K), D15.1 (K), D16.1 (K), D17.1 (K), D18.1 (K), D19.1 (K), D20.1 (K), D21.1 (K), D22.1 (K), D23.1 (K), D24.1 (K), D25.1 (K), D26.1 (K), J1.16
ROW2: D27.1 (K), D28.1 (K), D29.1 (K), D30.1 (K), D31.1 (K), D32.1 (K), D33.1 (K), D34.1 (K), D35.1 (K), D36.1 (K), D37.1 (K), D38.1 (K), D39.1 (K), J1.15
ROW3: D40.1 (K), D41.1 (K), D42.1 (K), D43.1 (K), D44.1 (K), D45.1 (K), D46.1 (K), D47.1 (K), D48.1 (K), D49.1 (K), D50.1 (K), D51.1 (K), D52.1 (K), J1.14
ROW4: D53.1 (K), D54.1 (K), D55.1 (K), D56.1 (K), D57.1 (K), D58.1 (K), D59.1 (K), D60.1 (K), D61.1 (K), D62.1 (K), D63.1 (K), D64.1 (K), D65.1 (K), J1.13
ROW5: D66.1 (K), D67.1 (K), D68.1 (K), D69.1 (K), D70.1 (K), D71.1 (K), D72.1 (K), D73.1 (K), D74.1 (K), D75.1 (K), D76.1 (K), D77.1 (K), D78.1 (K), J1.12
ROW6: D79.1 (K), D80.1 (K), D81.1 (K), D82.1 (K), D83.1 (K), D84.1 (K), D85.1 (K), D86.1 (K), D87.1 (K), D88.1 (K), D89.1 (K), D90.1 (K), D91.1 (K), J1.11
VCC: D92_Aug1.2 (A), D93_Dim1.2 (A), D94_Maj7.2 (A), D95_Dom7.2 (A), J1.1

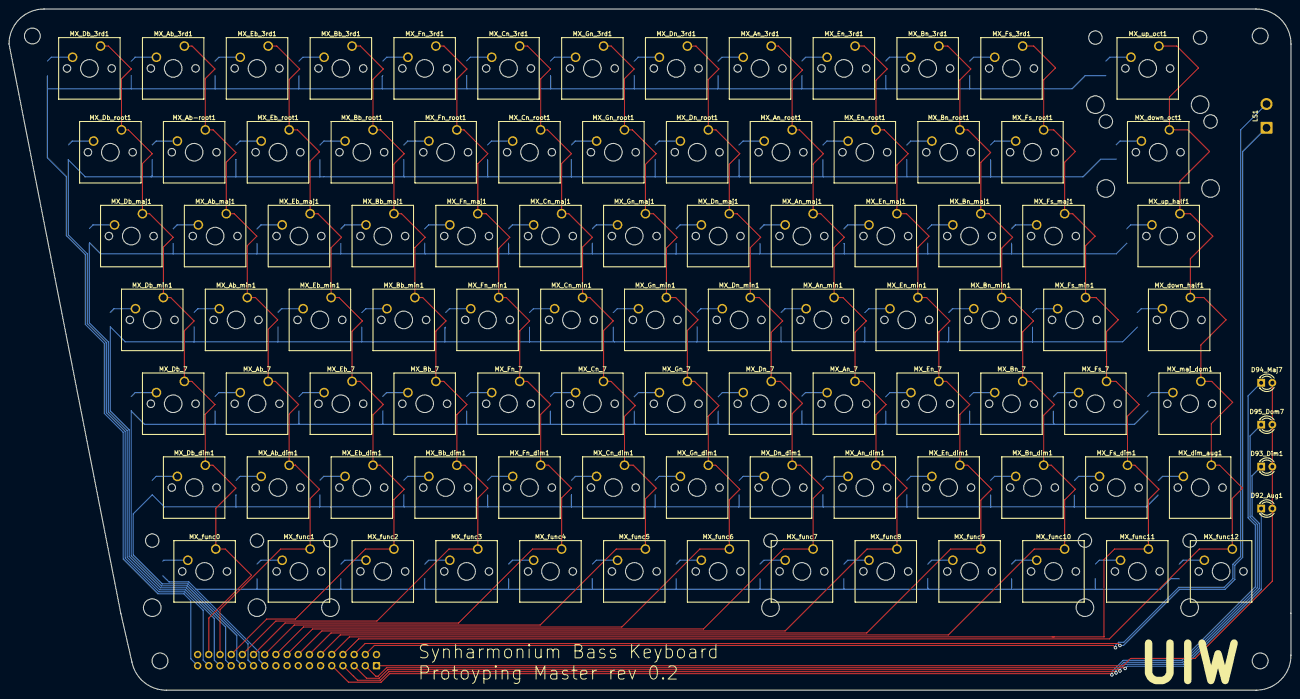
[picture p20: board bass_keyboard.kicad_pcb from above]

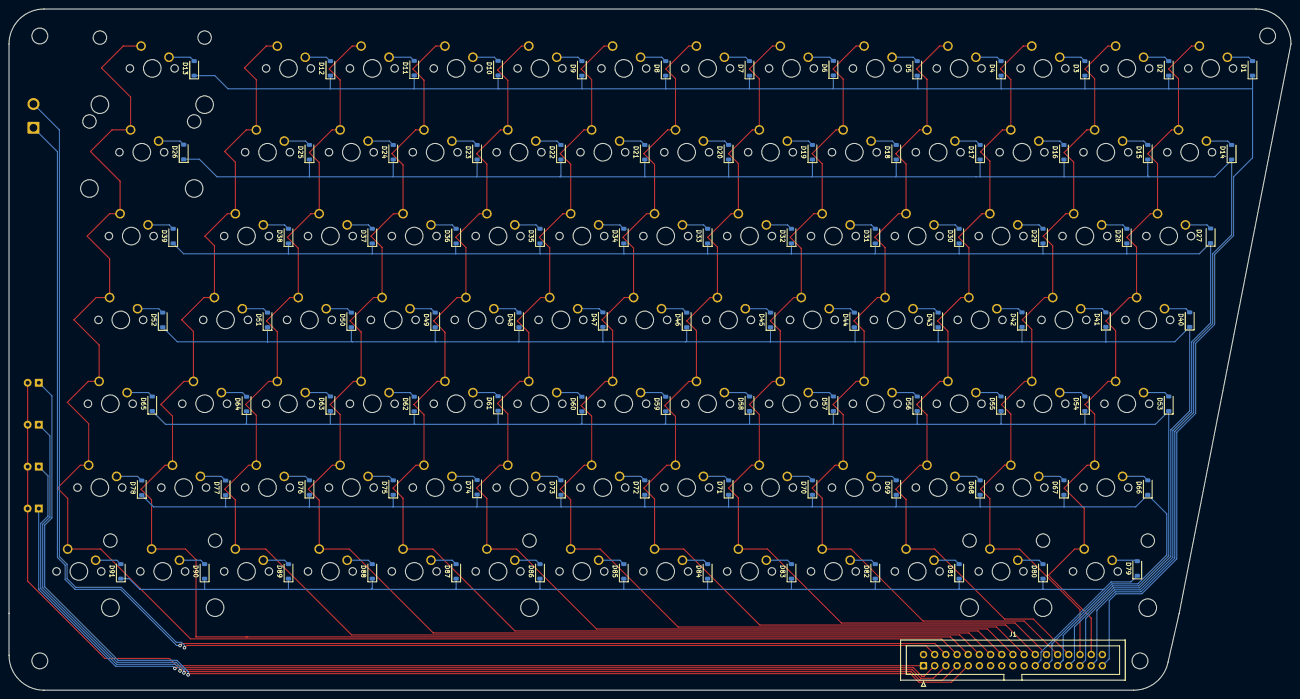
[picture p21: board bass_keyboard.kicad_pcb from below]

Board: 2 copper layers, 291.3 x 154.8 mm, 188 parts (92 on the bottom side), 118 nets.

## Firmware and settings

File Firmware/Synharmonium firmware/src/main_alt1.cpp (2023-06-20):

#include <Arduino.h>
#include <Keypad.h>

const byte ROWS = 7; //seven rows
const byte COLS = 13; //thirteen columns
char bassKeys[ROWS][COLS] = {
    // there need to be more unique values here than i can type, so we're just using an array of 
    // hexes which fits into ascii space. the characters they represent don't really matter, and 
    // they will be converted to something usable once out of the keymatrix library.
    {'\x00','\x01','\x02','\x03','\x04','\x05','\x06','\x07','\x08','\x09','\x0A','\x0B','\x0C'},  // thirds, up octave
    {'\x10','\x11','\x12','\x13','\x14','\x15','\x16','\x17','\x18','\x19','\x1A','\x1B','\x1C'},  // roots, down octave
    {'\x20','\x21','\x22','\x23','\x24','\x25','\x26','\x27','\x28','\x29','\x2A','\x2B','\x2C'},  // major chords, up half step
    {'\x30','\x31','\x32','\x33','\x34','\x35','\x36','\x37','\x38','\x39','\x3A','\x3B','\x3C'},  // minor chords, down half step
    {'\x40','\x41','\x42','\x43','\x44','\x45','\x46','\x47','\x48','\x49','\x4A','\x4B','\x4C'},  // 7th chords, major 7th vs dominant 7th toggle
    {'\x50','\x51','\x52','\x53','\x54','\x55','\x56','\x57','\x58','\x59','\x5A','\x5B','\x5C'},  // diminished or augmented chords, toggle between the two
    {'\x60','\x61','\x62','\x63','\x64','\x65','\x66','\x67','\x68','\x69','\x6A','\x6B','\x6C'}   // function row
};
byte rowPins[ROWS] = {32, 31, 30, 29, 28, 27, 26}; //connect to the row pinouts of the keypad
byte colPins[COLS] = {45, 44, 43, 42, 41, 40, 39, 38, 37, 36, 35, 34, 33}; //connect to the column pinouts of the keypad

Keypad bassKeyboard = Keypad( makeKeymap(bassKeys), rowPins, colPins, ROWS, COLS );

unsigned long loopCount;
unsigned long startTime;
String msg;

// microcontroller pinout, see /hardware/pinout_r***.ods
  // bass keyboard
    #define d92   22
    #define d93   23
    #define d94   24
    #define d95   25
    
    // #define row0  32
    // #define row1  31
    // #define row2  30
    // #define row3  29
    // #define row4  28
    // #define row5  27
    // #define row6  26

    // #define col0  45
    // #define col1  44
    // #define col2  43
    // #define col3  42
    // #define col4  41
    // #define col5  40
    // #define col6  39
    // #define col7  38
    // #define col8  37
    // #define col9  36
    // #define col10 35
    // #define col11 34
    // #define col12 33



// put function declarations here:


void setup() {
    Serial.begin(9600);
    loopCount = 0;
    startTime = millis();
    msg = "";
}

void loop() {
    loopCount++;
    if ( (millis()-startTime)>5000 ) {
        Serial.print("Average loops per second = ");
        Serial.println(loopCount/5);
        startTime = millis();
        loopCount = 0;
    }

    // Fills bassKeyboard.key[ ] array with up-to 10 active keys.
    // Returns true if there are ANY active keys.
    if (bassKeyboard.getKeys())
    {
        for (int i=0; i<LIST_MAX; i++)   // Scan the whole key list.
        {
            if ( bassKeyboard.key[i].stateChanged )   // Only find keys that have changed state.
            {
                switch (bassKeyboard.key[i].kstate) {  // Report active key state : IDLE, PRESSED, HOLD, or RELEASED
                    case PRESSED:
                    msg = " PRESSED.";
                break;
                    case HOLD:
                    msg = " HOLD.";
                break;
                    case RELEASED:
                    msg = " RELEASED.";
                break;
                    case IDLE:
                    msg = " IDLE.";
                }
                Serial.print("Key ");
                Serial.print(bassKeyboard.key[i].kchar);
                Serial.println(msg);
            }
        }
    }
}

// put function definitions here:

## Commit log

2021-12-22 Add submodules for bass keyboard
    [bass_keyboard.kicad_pcb, bass_keyboard.sch]
2021-12-23 Created switch matrix schematic
2021-12-24 Added labels to switches
    [bass_keyboard.sch]
2021-12-26 Added footprints for diodes
    Having trouble finding the footprints for the switches
    [bass_keyboard.sch]
2022-01-07 Added female connector
    Added the connector for the cable to the logic module on the bass keyboard schematic
    [bass_keyboard.sch]
2022-02-06 Update files to Kicad 6
    [bass_keyboard.kicad_pcb, bass_keyboard.kicad_sch]
2023-04-07 Future-proof bass keyboard
    Filled out the rest of the lower function row for futureproofing and expandability. Settled on a 2x16 pin header connector. Added indicator LEDs for the right side toggles, and speaker which is to be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
    [bass_keyboard.kicad_pcb, bass_keyboard.kicad_sch, bass_keyboard.sch]
2023-04-08 Begin Bass Keyboard PCB design
    Started placing switch footprints for the root row.
    [bass_keyboard.kicad_pcb, bass_keyboard.kicad_sch]
2023-04-12 Finishing layout, routing
    Got all of the footprints where they need to be, created the pcb outline, and used Freerouting to route connections, doing some final connections by hand.
    [bass_keyboard.dsn, bass_keyboard.kicad_pcb, bass_keyboard.kicad_sch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]
2023-04-12 Screwholes
    Added 4 screwholes at corners, tweaked bottom left corner.
    [bass_keyboard.kicad_pcb]
2023-04-12 Silkscreen labels
    Added model, part name, logo
    [bass_keyboard.kicad_pcb]
2023-04-12 Renders
    Replaced componentless led footprint with componentfull footprint. Rendered PCB with raytracing at a few angles.
    [bass_keyboard.kicad_pcb]
2023-04-23 Added DSA Keycap models
    [BOM.ods, BOM.xlsx, DAS 1.25u.step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]
2023-05-16 Redo traces on bass keyboard
    Completely started over on the traces, decided that the automatic routing was whack. Much happier with the new layout, increased orderliness and legibility, less prone to manufacturing error due to via clearance. Also adjusted speaker connection to better fit 16 AWG speaker wire.
    [bass_keyboard.kicad_pcb, bass_keyboard.kicad_sch, pinout r0.1.ods]
2023-05-20 Starting on Firmware
    Fumbling blindly into platform.io, trying to get initial keyscanning and midi functionality
    [pinout r0.1.ods]
2023-05-22 Prepared keycaps for 3d printing
    sliced, diced, 3mf'd
    [1.00.3mf, 1.00_homing.3mf, 1.00homing.3mf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]
2023-05-25 Added Website folder
    A custom web page will be hosted through github, and the source files will be stored here.
    [bass_keyboard.kicad_pcb]
2023-05-28 Begin modeling piano keys, 3d printing adjustments
    [1.3mf, keymodel_topC.FCStd]
2023-05-29 Html edits
    [keymodel_topC.FCStd]
2023-08-04 Explore alternatives for key matrix scanning
    [bass_keyboard.sch]
2023-10-09 Added Schematic PDF
